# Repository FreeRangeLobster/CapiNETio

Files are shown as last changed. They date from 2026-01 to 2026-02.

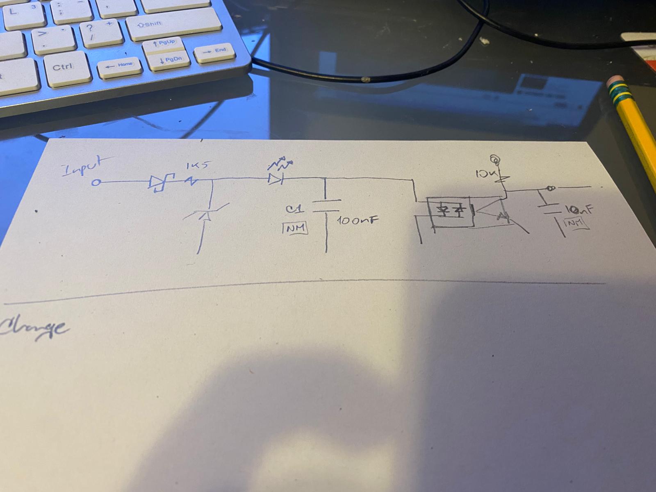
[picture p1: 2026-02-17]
Pics/InputCh.jpeg

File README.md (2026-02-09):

# CapiNETio

##To Do List:
* [x]Update all models
*[x] OK Add a new power connector 2 poles
*[x] OK Add a switch to allow power from the bus
*[x] OK Replace the 2 bus strips for one single one
*[x] OK create the layout and angle the in/Out Connectors
*[x] OK Check type of components and pcb constrains
*[]🔥  Show pull-up vs pull-down drive best practice

# Microcontroller

***Dip Switch
10 kΩ pull-up resistors (standard value)
Per input:
3.3V ── 10kΩ ── GPIO pin ── switch ── GND

Microcontroller output max per pin 

IO
Page73 of datasheet
Output current sunk by any I/O and control pin 25
Output current sourced by any I/Os and control pin - 25

LED current consumption
10ma

***LED indicators
Typical LED (553-0122F – red indicator)
Approximate specs (common for this part family):
• Forward voltage Vf ≈ 1.9–2.1 V
• Good brightness at 5–10 mA (no need to push 20 mA on STM32 pins)
STM32 GPIO max per pin is usually ~20 mA absolute max, but 5–8 mA is best practice.
Resistor calculation (3.3 V pin)
At 10 mA:
R = (3.3 − 2.0) / 0.01 = 130 Ω
At 5 mA (recommended for MCU safety):
R = (3.3 − 2.0) / 0.005 = 260 Ω

Best real-world values
Current	Resistor
~10 mA	150 Ω
~6 mA	220 Ω
~4 mA	330 Ω
use 220 Ω — bright enough and easy on the STM32 pin
   330 Ω if you want conservative current
Wiring
PA4 → resistor → LED → GND
(or LED to 3.3 V and pin sinks current — both fine)
⚠️ Important STM32
Try to keep:
≤ 8 mA per pin
≤ 100 mA total for the whole GPIO port

## Programming

# Power Supply

# RS485 bus

# Serial Comms

## Serial Comms USB
## Serial Comms

# Outputs

outputs relay, the LED calculations:
Device	Vf
551-0207-004F LED	~2.0 V
TLP290 LED	~1.2 V
Total	~3.2 V

STM32 output = 3.3 V

⚠️ T.hat leaves only:

3.3 − 3.2 = 0.1 V
not a good idea to put them in series. so need to be in parallel
GPIO → 390Ω → TLP290 LED → GND
GPIO → 1kΩ  → indicator LED → GND

# Inputs
***Inputs 5 to 24V. Pin3 inputs needs to be 0V common :

1.5 kΩ, 0.5 W resistor
5.1 V Zener diode (0.25 W or higher)
LEDs in series (indicator + opto)

indicator LED (551-0207-004F) in series with the TLP290 LED and a requirement that it must reliably turn ON already at 5 V, we should bias this a bit stronger than the “borderline” case and still keep it safe at 24 V.

 Known drops (worst-case friendly)

Typical at a few mA:

• Indicator LED ≈ 2.0 V
• TLP290 LED ≈ 1.2 V

👉 Total ≈ 3.2 V

🎯 Target currents

To guarantee turn-on across temperature & aging:

✅ Minimum at 5 V → ≈2 mA
✅ Normal at 24 V → 6–10 mA

This keeps CTR healthy and LEDs safe.

🧩 Use Zener clamp (still the right approach)

Clamp voltage: 5.1 V

So effective resistor voltage at clamp:

5.1 − 3.2 = 1.9 V

🧮 Pick resistor for strong low-end + safe high-end

Let’s choose R = 1.5 kΩ (this is the sweet spot now).

📊 Check operation
✅ At 5 V input (no heavy clamp yet):
I ≈ (5 − 3.2) / 1.5k ≈ 1.2 mA

Plus clamp assistance as it approaches 5.1 V → roughly 1.5–2 mA effective

Enough to switch TLP290 reliably.

✅ At 24 V input (clamped):
I ≈ (24 − 5.1) / 1.5k ≈ 12.6 mA

Still within safe continuous LED current.

Power check (important)

Resistor:

P ≈ I²R ≈ (0.0126)² × 1500 ≈ 0.24 W

👉 Use ½ W resistor (recommended for longevity)

Zener:

P ≈ 5.1 × 0.0126 ≈ 64 mW

Any 0.25 W zener is fine.

✅ Final rugged values (guaranteed 5–24 V)
Input side:

🟢 1.5 kΩ, 0.5 W resistor
🟢 5.1 V Zener diode (0.25 W or higher)
🟢 LEDs in series (indicator + opto)

📌 Conclusion

✔ Turns ON at 5 V every time
✔ Safe at 24 V continuously
✔ Good noise margin
✔ Long LED life

Good to Add:
✔️ Add reverse polarity protection diode
✔️ Add surge suppressor (TVS)
✔️ Show exact schematic symbol placement

Zener options:

Here are some **good SMD Zener diode options you can use as your 5.1 V clamp on the input side of your optocoupler circuit (to clamp voltage around ~5.1 V for a 1.5 kΩ series resistor):

Nexperia BZX884‑C5V1 Zener Diode
€0.19
•
JAK Electronics + others
onsemi MMBZ5231ELT1G Zener Diode
€0.26
•
DigiKey Italy
DiodesZetex 5.1V Zener (SMD)
€0.26
•
DigiKey Italy
Vishay BZM55C5V1TR MicroMELF Zener
€0.17
•
DigiKey Italy + others
ROHM PDZVTFTR5.1B Zener Diode
€0.39
•
Mouser Italia
ROHM KDZVTFTR5.1B Zener Diode
€0.54
•
Mouser Italia
onsemi 1SMB5918BT3G 5.1 V Zener
€0.64
•
Mouser Italia
Vishay AEC‑Q101 5.1 V Zener (automotive)
€15.80
•
RS Italy
🟡 Best general-purpose low-power (0.25–0.35 W)

These are ideal for clamping in your optocoupler input. Typical power rating ~250–350 mW which is enough for ~5–10 mA clamp:

Nexperia BZX884‑C5V1 Zener Diode – SOT-23, very common, cheap, 5.1 V clamp.

onsemi MMBZ5231ELT1G Zener Diode – another SOT-23 5.1 V option at low cost.

DiodesZetex 5.1V Zener (SMD) – generic 5.1 V Zener in compact SMD package.

Vishay BZM55C5V1TR MicroMELF Zener – MicroMELF style, tiny but robust.

ROHM PDZVTFTR5.1B Zener Diode – well-known brand part.

🟢 Higher power / automotive or robust

If you want more clamp headroom or automotive spec:

ROHM KDZVTFTR5.1B Zener Diode – similar to above with slightly different rating.

onsemi 1SMB5918BT3G 5.1 V Zener – much higher power, overkill for this but good for surge protection too.

Vishay AEC‑Q101 5.1 V Zener (automotive) – automotive-grade if you need rugged industrial reliability.

📌 How to choose

✔ For typical PCB input clamping and currents ~5-10 mA: go with BZX884-C5V1 or MMBZ5231ELT1G in SOT-23 — they are small, cheap, and easy to place.
✔ For power handling or are worried about surges, pick a 500 mW part like ROHM or larger packages.

BZX884-C5V1

D1 – SS14 / BAT54 (Schottky)
R1 – 1.5kΩ 0.5W
ZD1 – 5.1V SMD Zener (SOT-23 or SOD-123)
R2 – 10kΩ
LED1 – 551-0207-004F
LED2 – TLP290

# Cheat sheet

git push -u origin main

Kicad tutorial stm32
https://www.youtube.com/watch?v=aVUqaB0IMh4
KiCad 6 STM32 PCB Design Full Tutorial - Phil's Lab #65

Songs:

nati botero te quiero mucho, ponka el problemon, no todo puede llamarse amor jorge celedon, todo de cabeza, la indiferencia de silvestre dangon, labios compartidos, amor de verano eddie, pump it black eyed peas, sexy back justin, i wann love you akon, crazy knarrls barkley, gwen stefany sh=weetes, rehab amy winehouse, bad date daniel, welcome to the black parade, supermassive blackhole muse, snow red hot chilly pepers,

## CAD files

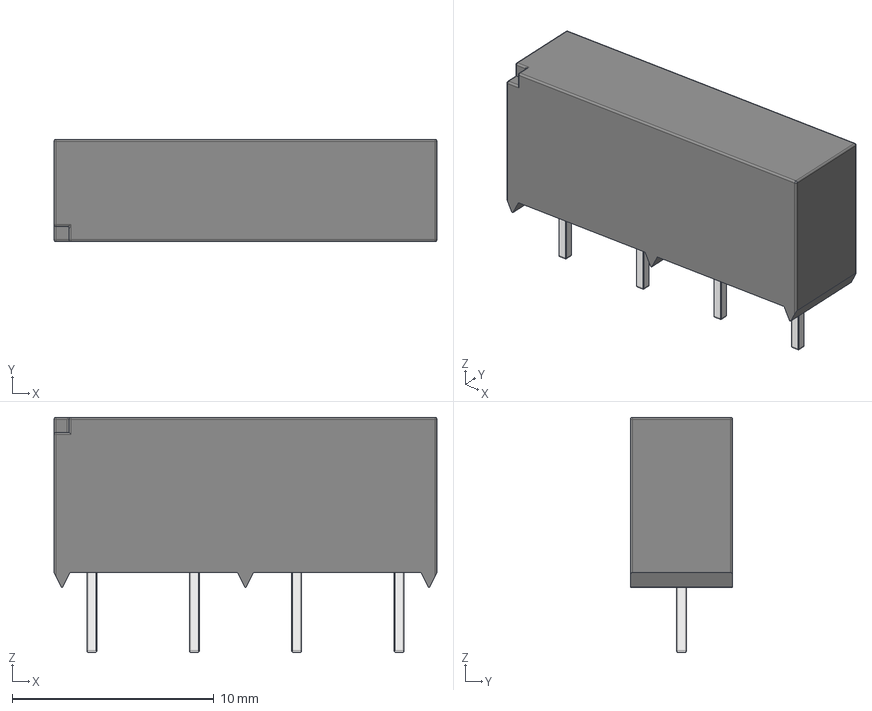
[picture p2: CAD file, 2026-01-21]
CadModels/3570-1333-051/Reed Relay Comus 3570 1331.stp
19.0 x 5.08 x 11.7 mm
Gehäuse
Pin x 4

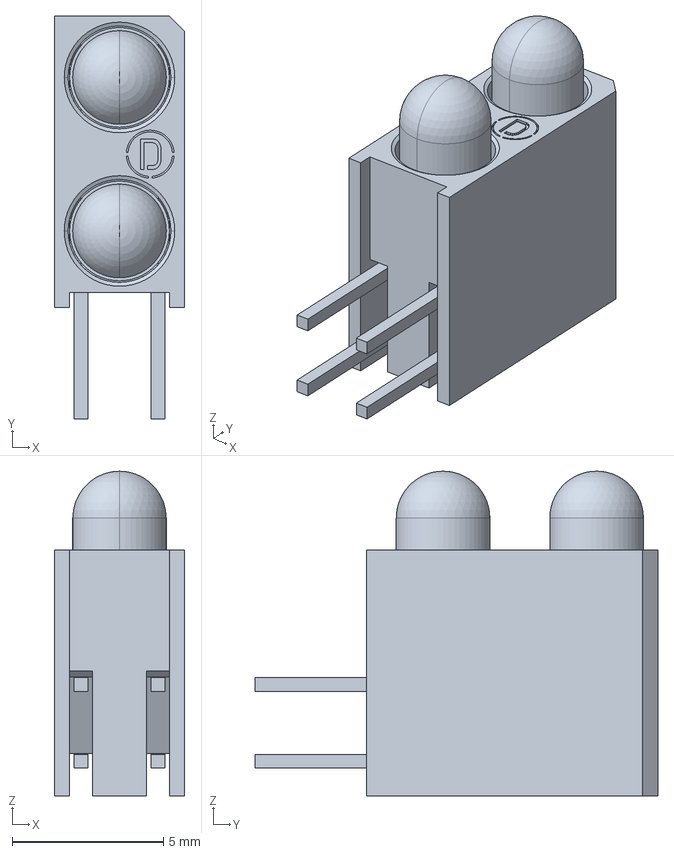
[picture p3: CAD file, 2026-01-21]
CadModels/553-0122F/3D/553-0122F.stp
4.32 x 13.3 x 10.7 mm

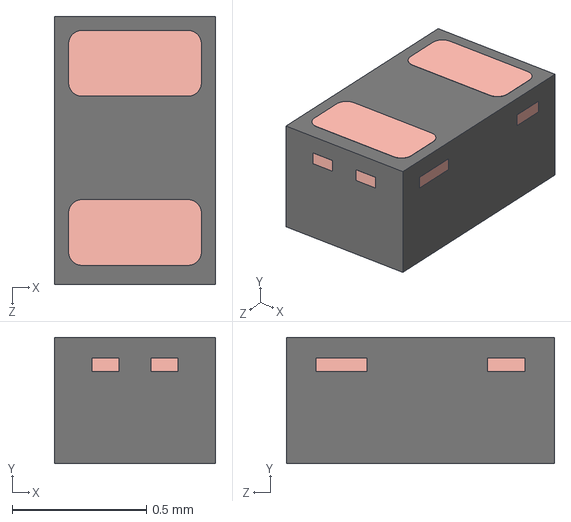
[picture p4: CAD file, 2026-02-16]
CadModels/BZX884-C5V1-QYL_ZenerDiode/SOD882.step
0.6 x 0.471 x 1.00 mm
SOD882 body
SOD882A3 singulated LF unit

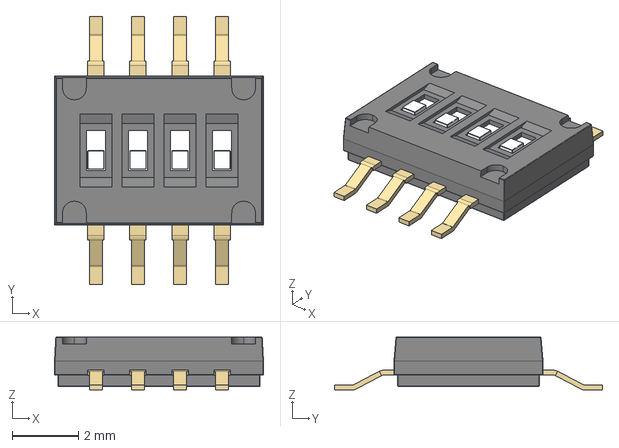
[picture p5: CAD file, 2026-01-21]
CadModels/DipSw_DHNF04F/3D/DHNF-04F-T-V-T_R.stp
6.31 x 8.10 x 1.60 mm

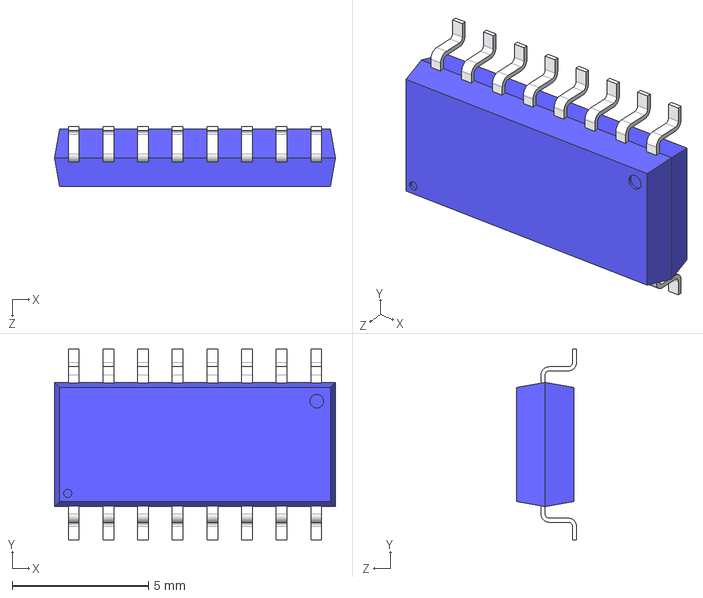
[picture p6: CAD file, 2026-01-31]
CadModels/OptoTLP290-4/TLP290-4_TP,E.stp
10.3 x 7.00 x 2.20 mm

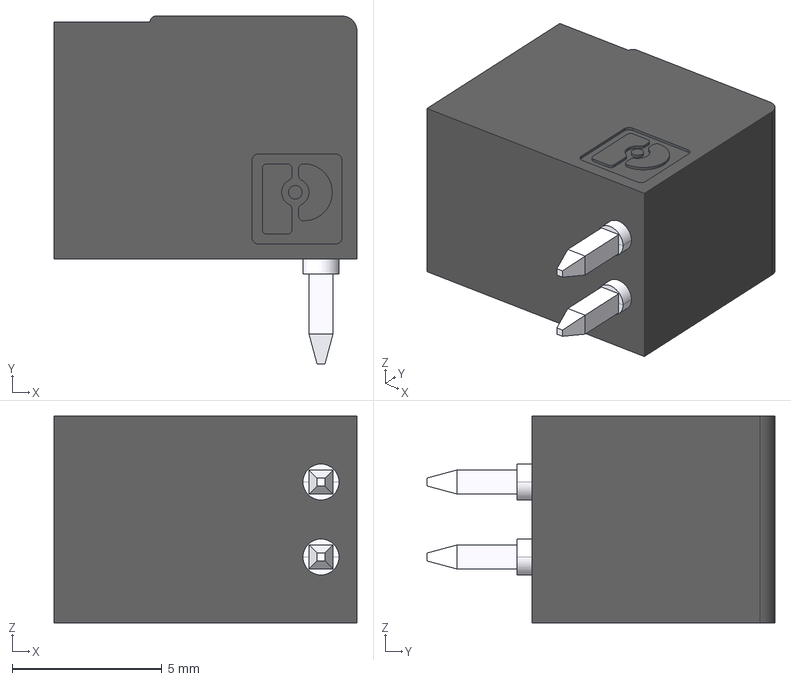
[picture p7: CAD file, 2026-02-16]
CadModels/1963421_2Poles_Connector/3D/1963421.stp
10.1 x 11.6 x 6.90 mm

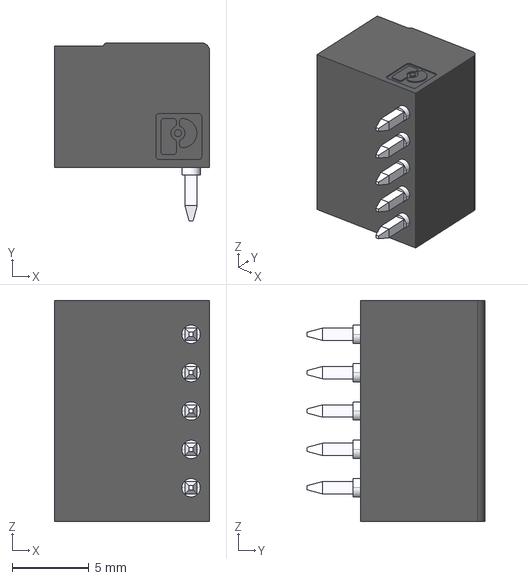
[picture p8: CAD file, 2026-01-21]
CadModels/1963450PCBConnector/1963450.stp
10.1 x 11.6 x 14.4 mm

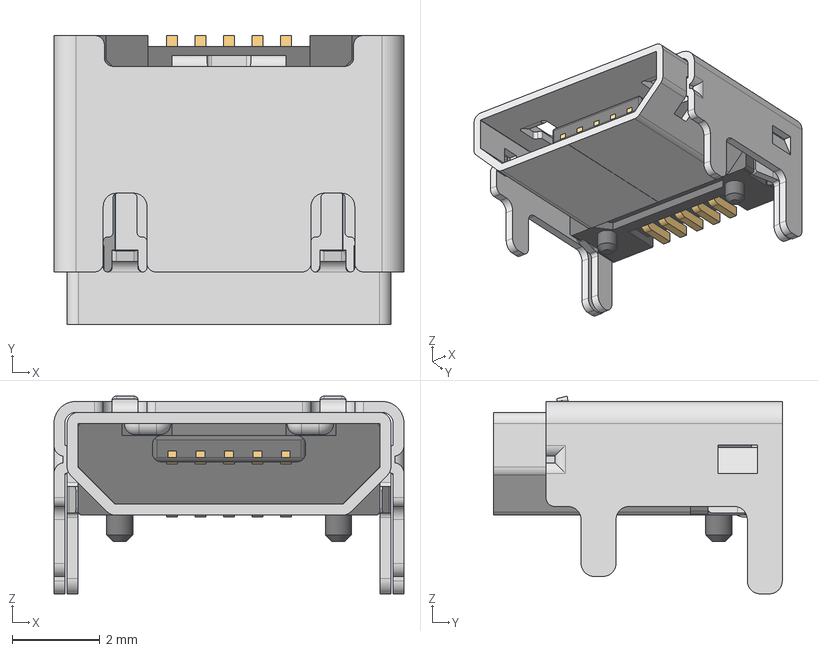
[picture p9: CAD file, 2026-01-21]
CadModels/629105150521%20%28rev1%29.stp
8.00 x 6.60 x 4.52 mm
629105150521_Housing
629105150521_Pin1 x 4
629105150521_Pin2
629105150521_Shielding2
629105150521_Shielding

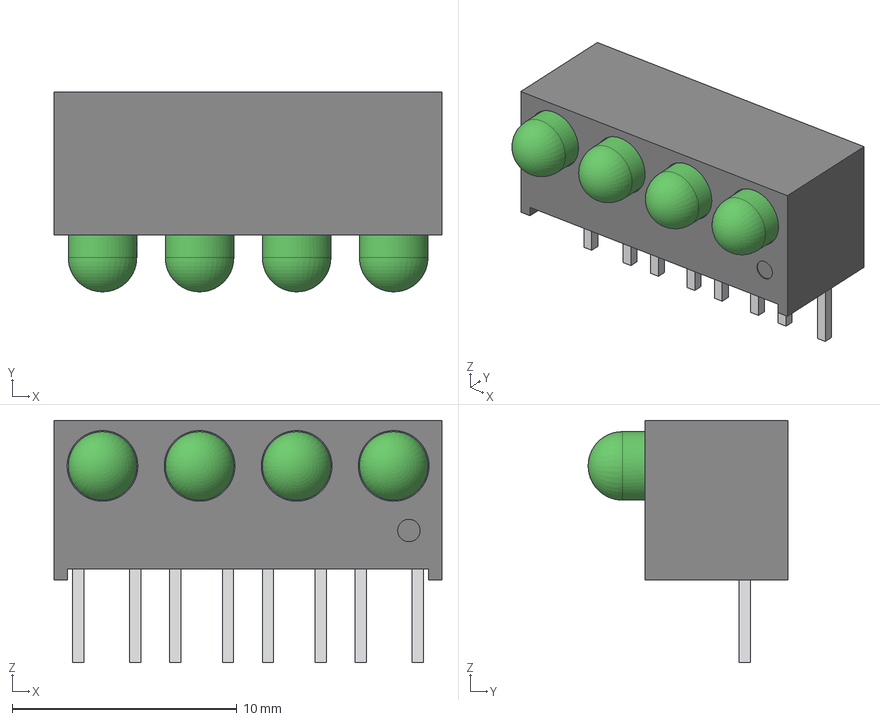
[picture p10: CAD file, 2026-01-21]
CadModels/LED Array 551-0207-004F/3D/5510207004F.stp
17.3 x 8.89 x 10.8 mm

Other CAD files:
CadModels/1963421_2Poles_Connector/Allegro/1963421.psm
CadModels/1963421_2Poles_Connector/DEHDL/1963421/chips/chips.prt
CadModels/553-0122F/Allegro/5530122f.psm
CadModels/553-0122F/DEHDL/553_0122f/chips/chips.prt
CadModels/DipSw_DHNF04F/Allegro/dhnf04ftvtr.psm
CadModels/DipSw_DHNF04F/DEHDL/dhnf_04f_t_v_t_r/chips/chips.prt
CadModels/LED Array 551-0207-004F/Allegro/5510207004f.psm
CadModels/LED Array 551-0207-004F/DEHDL/551_0207_004f/chips/chips.prt

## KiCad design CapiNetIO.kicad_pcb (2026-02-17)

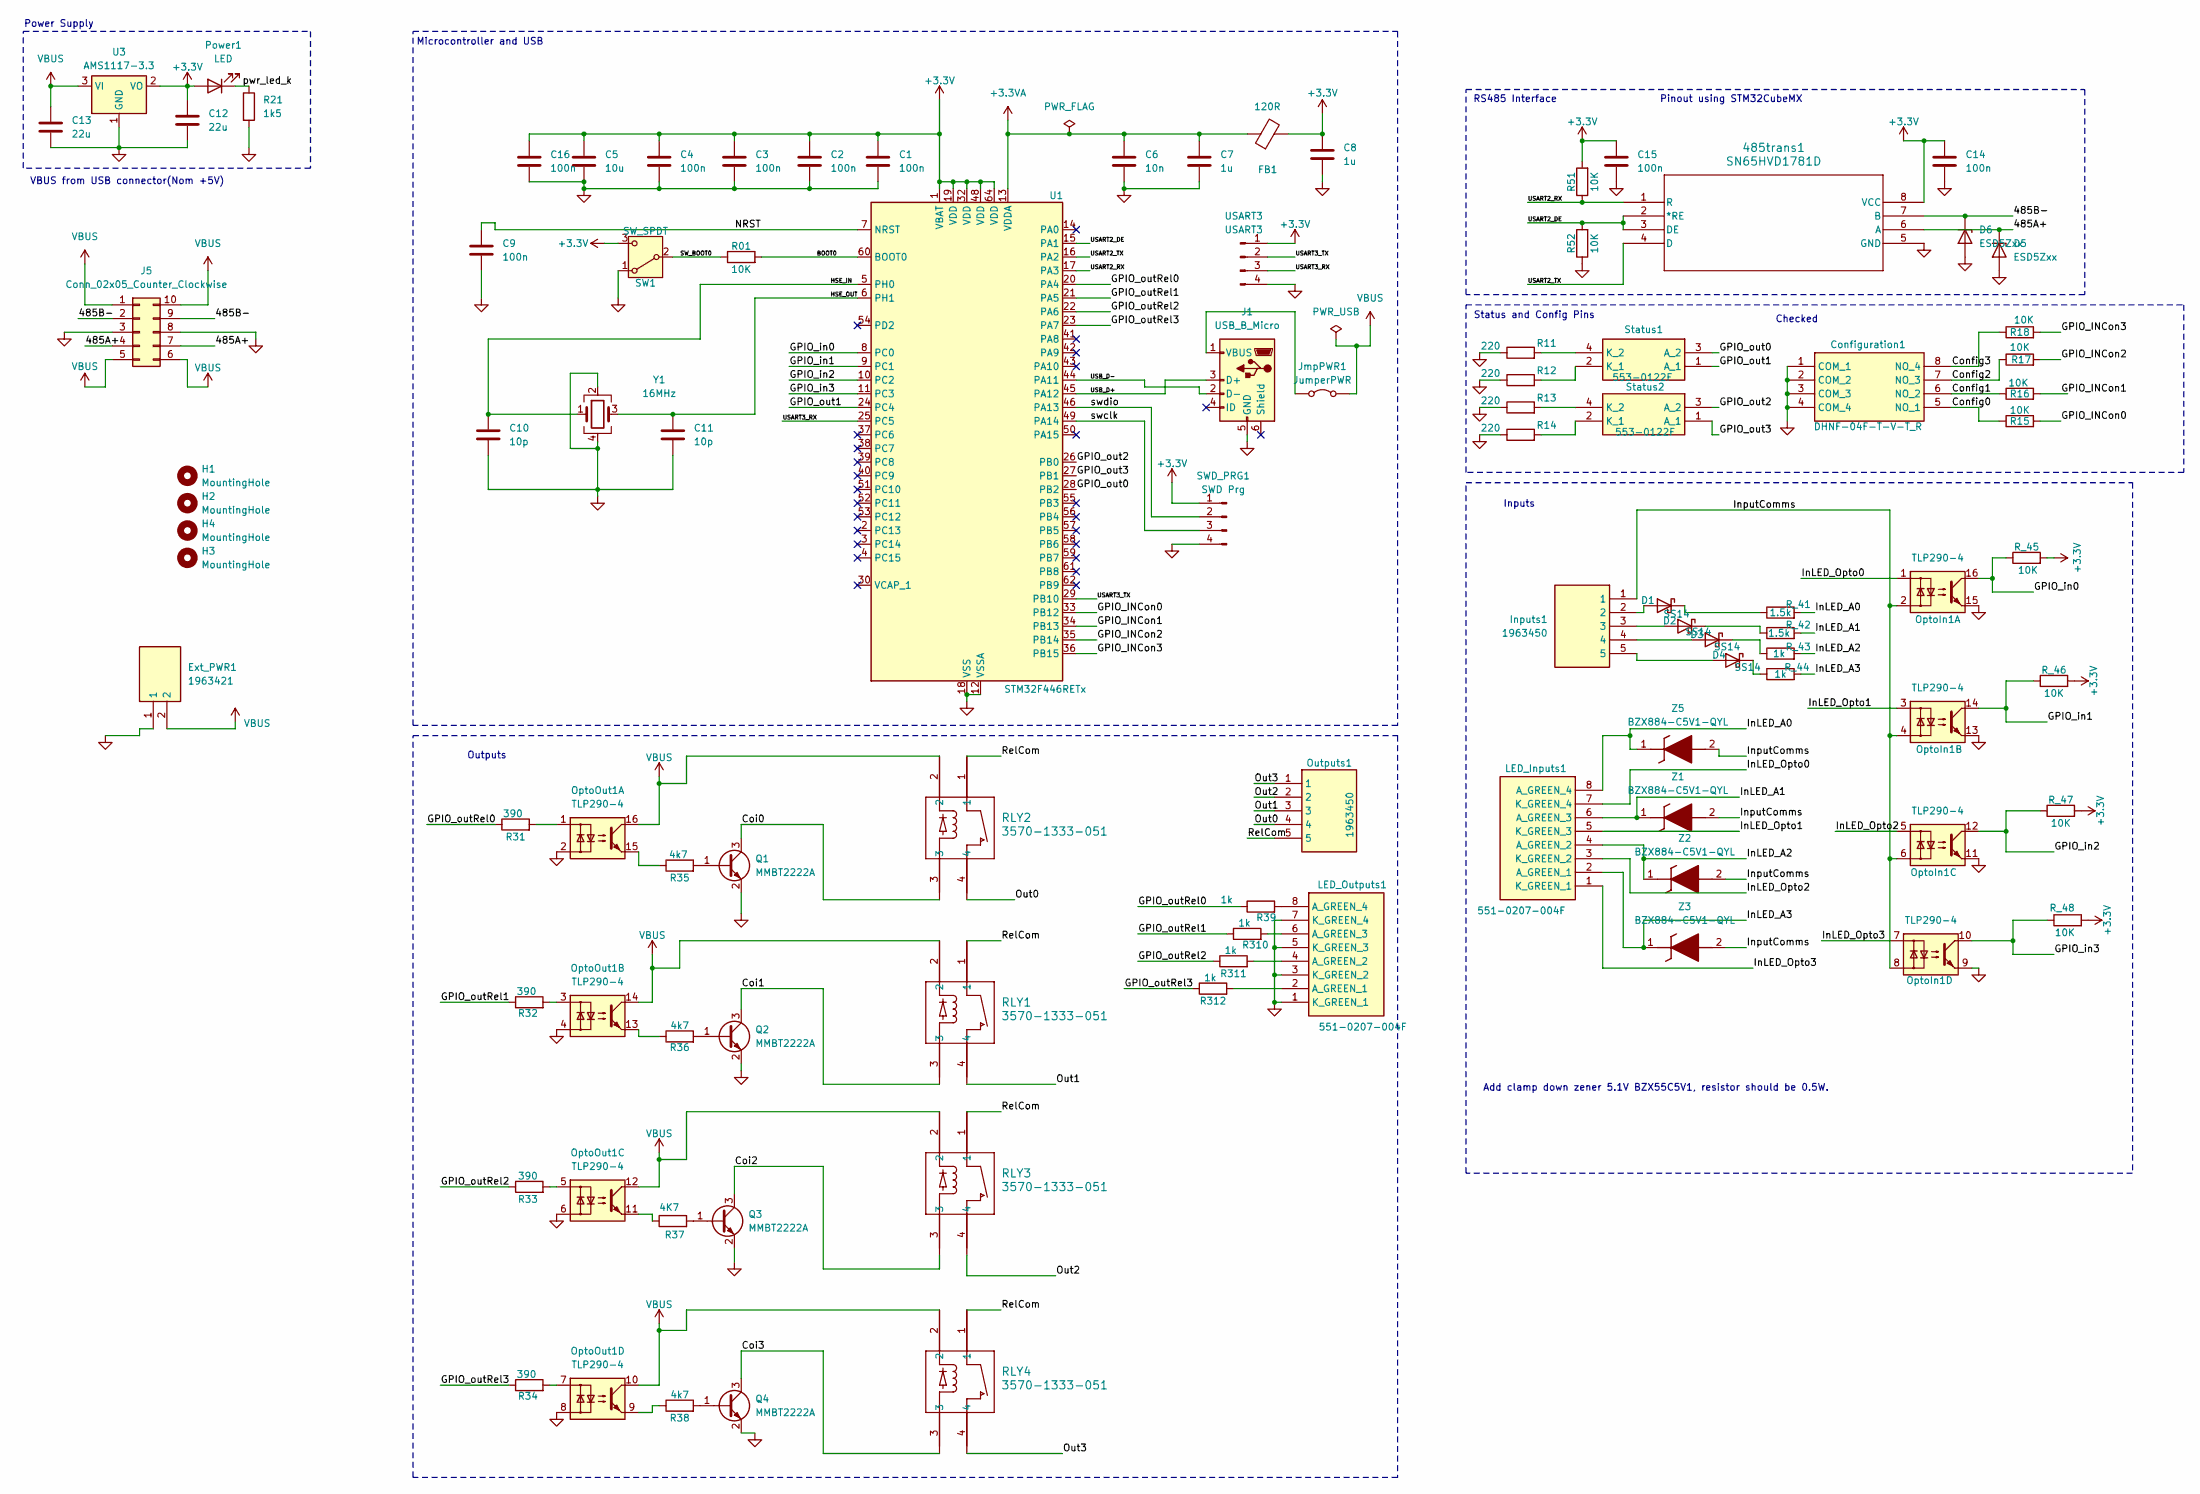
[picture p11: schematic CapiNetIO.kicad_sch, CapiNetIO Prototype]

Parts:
485trans1: SN65HVD1781D
C1, C2, C3, C4, C9, C14, C15, C16: 100n; C_0603_1608Metric
C5: 10u; C_0603_1608Metric
C6: 10n; C_0603_1608Metric
C7, C8: 1u; C_0603_1608Metric
C10, C11: 10p; C_0603_1608Metric
C12, C13: 22u; C_0805_2012Metric
Configuration1: DHNF-04F-T-V-T_R; DHNF04FTVTR; Mouser Part Number 113-DHNF04FTVTR
D1, D2, D3, D4: SS14; D_SMA
D5, D6: ESD5Zxx; D_SOD-523
Ext_PWR1: 1963421; Manufacturer_Part_Number 1963421
FB1: 120R; L_0603_1608Metric
H1, H2, H3, H4: MountingHole; MountingHole_3.5mm
Inputs1: 1963450; Manufacturer_Part_Number 1963450; Mouser Part Number 651-1963450
J1: USB_B_Micro; USB_Micro-B_Wuerth_629105150521
J5: Conn_02x05_Counter_Clockwise; IDC-Header_2x05_P2.54mm_Vertical
JmpPWR1: JumperPWR; TestPoint_2Pads_Pitch2.54mm_Drill0.8mm
LED_Inputs1: 551-0207-004F; 5510207004F; Manufacturer_Part_Number 551-0207-004F
LED_Outputs1: 551-0207-004F; 5510207004F; Manufacturer_Part_Number 551-0207-004F
OptoIn1: TLP290-4; SOP-16_4.55x10.3mm_P1.27mm
OptoOut1: TLP290-4; SOP-16_4.55x10.3mm_P1.27mm
Outputs1: 1963450; Manufacturer_Part_Number 1963450; Mouser Part Number 651-1963450
Power1: LED; LED_0603_1608Metric
Q1, Q2, Q3, Q4: MMBT2222A; SOT-23
R01, R15, R16, R17, R18, R51, R52: 10K; R_0402_1005Metric
R11, R12, R13, R14: 220; R_0402_1005Metric
R21: 1k5; R_0402_1005Metric
R31, R32, R33, R34: 390; R_0402_1005Metric
R35, R36, R38: 4k7; R_0402_1005Metric
R37: 4K7; R_0402_1005Metric
R39, R310, R311, R312: 1k; R_0402_1005Metric
RLY1, RLY2, RLY3, RLY4: 3570-1333-051; RELAY4_3570-1333-051_COM
R_41, R_42: 1.5k; R_0402_1005Metric
R_43, R_44: 1k; R_0402_1005Metric
R_45, R_46, R_47, R_48: 10K; R_0402_1005Metric
SW1: SW_SPDT; SW_SPDT_PCM12
SWD_PRG1: SWD Prg; PinHeader_1x04_P2.54mm_Horizontal
Status1, Status2: 553-0122F; 5530122F; Mouser Part Number 645-553-0122F
U1: STM32F446RETx; LQFP-64_10x10mm_P0.5mm
U3: AMS1117-3.3; SOT-223-3_TabPin2
USART3: USART3; PinHeader_1x04_P2.54mm_Horizontal
Y1: 16MHz; Crystal_SMD_3225-4Pin_3.2x2.5mm
Z1, Z2, Z3, Z5: BZX884-C5V1-QYL; BZX884C5V1QYL; Manufacturer_Part_Number BZX884-C5V1-QYL

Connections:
+3.3V: 485trans1.8 (VCC), C1.1, C2.1, C3.1, C4.1, C5.1, C8.1, C12.1, C14.1, C15.1, C16.1, FB1.2, Power1.2 (A), R51.2, R_45.2, R_46.2, R_47.2, R_48.2, SW1.3 (C), SWD_PRG1.1, U1.1 (VBAT), U1.19 (VDD), U1.32 (VDD), U1.48 (VDD), U1.64 (VDD), U3.2 (VO), USART3.1
+3.3VA: C6.1, C7.1, FB1.1, U1.13 (VDDA)
/485A+: 485trans1.6 (A), D5.1 (K), J5.4, J5.7
/485B-: 485trans1.7 (B), D6.1 (K), J5.2, J5.9
/BOOT0: R01.2, U1.60 (BOOT0)
/Coi0: Q1.3 (C), RLY2.3
/Coi1: Q2.3 (C), RLY1.3
/Coi2: Q3.3 (C), RLY3.3
/Coi3: Q4.3 (C), RLY4.3
/Config0: Configuration1.5 (NO_1), R15.1
/Config1: Configuration1.6 (NO_2), R16.1
/Config2: Configuration1.7 (NO_3), R17.1
/Config3: Configuration1.8 (NO_4), R18.1
/GPIO_INCon0: R15.2, U1.33 (PB12)
/GPIO_INCon1: R16.2, U1.34 (PB13)
/GPIO_INCon2: R17.2, U1.35 (PB14)
/GPIO_INCon3: R18.2, U1.36 (PB15)
/GPIO_in0: OptoIn1.16, R_45.1, U1.8 (PC0)
/GPIO_in1: OptoIn1.14, R_46.1, U1.9 (PC1)
/GPIO_in2: OptoIn1.12, R_47.1, U1.10 (PC2)
/GPIO_in3: OptoIn1.10, R_48.1, U1.11 (PC3)
/GPIO_out0: Status1.3 (A_2), U1.28 (PB2)
/GPIO_out1: Status1.1 (A_1), U1.24 (PC4)
/GPIO_out2: Status2.3 (A_2), U1.26 (PB0)
/GPIO_out3: Status2.1 (A_1), U1.27 (PB1)
/GPIO_outRel0: R31.1, R39.1, U1.20 (PA4)
/GPIO_outRel1: R32.1, R310.1, U1.21 (PA5)
/GPIO_outRel2: R33.1, R311.1, U1.22 (PA6)
/GPIO_outRel3: R34.1, R312.1, U1.23 (PA7)
/HSE_IN: C10.1, U1.5 (PH0), Y1.1
/HSE_OUT: C11.1, U1.6 (PH1), Y1.3
/InLED_A0: LED_Inputs1.8 (A_GREEN_4), R_41.2, Z5.1 (K)
/InLED_A1: LED_Inputs1.6 (A_GREEN_3), R_42.2, Z1.1 (K)
/InLED_A2: LED_Inputs1.4 (A_GREEN_2), R_43.2, Z2.1 (K)
/InLED_A3: LED_Inputs1.2 (A_GREEN_1), R_44.2, Z3.1 (K)
/InLED_Opto0: LED_Inputs1.7 (K_GREEN_4), OptoIn1.1
/InLED_Opto1: LED_Inputs1.5 (K_GREEN_3), OptoIn1.3
/InLED_Opto2: LED_Inputs1.3 (K_GREEN_2), OptoIn1.5
/InLED_Opto3: LED_Inputs1.1 (K_GREEN_1), OptoIn1.7
/InputComms: Inputs1.1, OptoIn1.2, OptoIn1.4, OptoIn1.6, OptoIn1.8, Z1.2 (A), Z2.2 (A), Z3.2 (A), Z5.2 (A)
/NRST: C9.1, U1.7 (NRST)
/Out0: Outputs1.4, RLY2.4
/Out1: Outputs1.3, RLY1.4
/Out2: Outputs1.2, RLY3.4
/Out3: Outputs1.1, RLY4.4
/RelCom: Outputs1.5, RLY1.1, RLY2.1, RLY3.1, RLY4.1
/SW_BOOT0: R01.1, SW1.2 (B)
/USART2_DE: 485trans1.2 (*RE), 485trans1.3 (DE), R52.2, U1.15 (PA1)
/USART2_RX: 485trans1.1 (R), R51.1, U1.17 (PA3)
/USART2_TX: 485trans1.4 (D), U1.16 (PA2)
/USART3_RX: U1.25 (PC5), USART3.3
/USART3_TX: U1.29 (PB10), USART3.2
/USB_D+: J1.3 (D+), U1.45 (PA12)
/USB_D-: J1.2 (D-), U1.44 (PA11)
/pwr_led_k: Power1.1 (K), R21.1
/swclk: SWD_PRG1.3, U1.49 (PA14)
/swdio: SWD_PRG1.2, U1.46 (PA13)
GND: 485trans1.5 (GND), C1.2, C2.2, C3.2, C4.2, C5.2, C6.2, C7.2, C8.2, C9.2, C10.2, C11.2, C12.2, C13.2, C14.2, C15.2, C16.2, Configuration1.1 (COM_1), Configuration1.2 (COM_2), Configuration1.3 (COM_3), Configuration1.4 (COM_4), D5.2 (A), D6.2 (A), Ext_PWR1.1, J1.5 (GND), J5.3, J5.8, LED_Outputs1.1 (K_GREEN_1), LED_Outputs1.3 (K_GREEN_2), LED_Outputs1.5 (K_GREEN_3), LED_Outputs1.7 (K_GREEN_4), OptoIn1.9, OptoIn1.11, OptoIn1.13, OptoIn1.15, OptoOut1.2, OptoOut1.4, OptoOut1.6, OptoOut1.8, Q1.2 (E), Q2.2 (E), Q3.2 (E), Q4.2 (E), R11.1, R12.1, R13.1, R14.1, R21.2, R52.1, SW1.1 (A), SWD_PRG1.4, U1.12 (VSSA), U1.18 (VSS), U1.31 (VSS), U1.47 (VSS), U1.63 (VSS), U3.1 (GND), USART3.4, Y1.2, Y1.4
unnamed: D1.2 (A), Inputs1.2
unnamed: D1.1 (K), R_41.1
unnamed: D2.2 (A), Inputs1.3
unnamed: D2.1 (K), R_42.1
unnamed: D3.2 (A), Inputs1.4
unnamed: D3.1 (K), R_43.1
unnamed: D4.2 (A), Inputs1.5
unnamed: D4.1 (K), R_44.1
unnamed: J1.1 (VBUS), JmpPWR1.1 (A)
unnamed: LED_Outputs1.2 (A_GREEN_1), R312.2
unnamed: LED_Outputs1.4 (A_GREEN_2), R311.2
unnamed: LED_Outputs1.6 (A_GREEN_3), R310.2
unnamed: LED_Outputs1.8 (A_GREEN_4), R39.2
unnamed: OptoOut1.1, R31.2
unnamed: OptoOut1.3, R32.2
unnamed: OptoOut1.5, R33.2
unnamed: OptoOut1.7, R34.2
unnamed: OptoOut1.9, R38.1
unnamed: OptoOut1.11, R37.1
unnamed: OptoOut1.13, R36.1
unnamed: OptoOut1.15, R35.1
unnamed: Q1.1 (B), R35.2
unnamed: Q2.1 (B), R36.2
unnamed: Q3.1 (B), R37.2
unnamed: Q4.1 (B), R38.2
unnamed: R12.2, Status1.2 (K_1)
unnamed: R11.2, Status1.4 (K_2)
unnamed: R14.2, Status2.2 (K_1)
unnamed: R13.2, Status2.4 (K_2)
VBUS: C13.1, Ext_PWR1.2, J5.1, J5.5, J5.6, J5.10, JmpPWR1.2 (B), OptoOut1.10, OptoOut1.12, OptoOut1.14, OptoOut1.16, RLY1.2, RLY2.2, RLY3.2, RLY4.2, U3.3 (VI)

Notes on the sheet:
Microcontroller and USB
Power Supply
VBUS from USB connector(Nom +5V)
Pinout using STM32CubeMX
Status and Config Pins
Add clamp down zener 5.1V BZX55C5V1, resistor should be 0.5W.
Inputs
Checked
Outputs
RS485 Interface

Board: 2 copper layers, 92 parts (0 on the bottom side), 88 nets, no tracks yet.

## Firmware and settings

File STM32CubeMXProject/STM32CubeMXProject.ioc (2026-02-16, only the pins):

Mcu.UserName=STM32F446RETx
PA13.Signal=SYS_JTMS-SWDIO
PA14.Signal=SYS_JTCK-SWCLK
PB0.Signal=GPIO_Output
PB1.Signal=GPIO_Output
PB2.Signal=GPIO_Output
PC0.Signal=GPIO_Input
PC1.Signal=GPIO_Input
PC2.Signal=GPIO_Input
PC3.Signal=GPIO_Input
PC4.Signal=GPIO_Output

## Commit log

2026-01-23 checking components are present in pcb and renaming
    [CapiNetIO.kicad_pcb, CapiNetIO.kicad_sch]
2026-01-28 Updating models
    [CapiNetIO.kicad_pcb, CapiNetIO.kicad_sch]
2026-01-31 Status and dipswitches, checked, working on inputs
    [CapiNetIO.kicad_pcb, CapiNetIO.kicad_sch, TLP290-4_TP,E.stp]
2026-02-02 checked outputs for resistors and circuits
    [CapiNetIO.kicad_pcb, CapiNetIO.kicad_sch]
2026-02-03 updated inter PCB bus, added jumper power from USB
    [CapiNetIO.kicad_pcb, CapiNetIO.kicad_sch]
2026-02-04 Overall Check, need to update the pbc constrains to pass checks
    [CapiNetIO.kicad_pcb, CapiNetIO.kicad_sch]
2026-02-09 Checked footprints and pcb constrains, time to start tracing
    [CapiNetIO.kicad_pcb, CapiNetIO.kicad_sch]
2026-02-16 Changed pins GPIO_Out0-3 and GPIO_In0-3 to a more accessible ones. Added project CubeMX
    [1963421.psm, 1963421.stp, CapiNetIO.kicad_pcb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]
2026-02-17 working on the pcb side, tidying up io
    [CapiNetIO.kicad_pcb, CapiNetIO.kicad_sch]
